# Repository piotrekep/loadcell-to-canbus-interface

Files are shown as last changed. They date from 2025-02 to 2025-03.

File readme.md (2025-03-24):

# Digital Scale with CAN Bus

This repository contains firmware for a digital scale system based on the ATmega328 microcontroller. Developed over 10 years ago, this project reads analog data via an ADS1234 ADC and transmits measurements over a CAN bus using an MCP2515 controller through an SPI interface.

## Overview

The firmware implements a digital weighing system that:

- **Acquires Data**: Reads four channels of analog data from an ADS1234 ADC.
- **CAN Bus Communication**: Transmits the acquired data in two separate CAN messages (IDs 0x250 and 0x251).
- **SPI Interface**: Uses custom SPI routines to communicate with both the CAN controller and the ADS1234.
- **Robust Operation**: Utilizes a watchdog timer and interrupt-driven routines to ensure reliable operation.

## Hardware Setup

### ATmega328
- **Microcontroller**: ATmega328
- **Clock Speed**: 20 MHz (FOSC = 20,000,000)

### ADS1234 ADC
- **Data Acquisition**:
  - **Input Selection**: Controlled via two pins on PORTC (A0 on PC1 and A1 on PC0).
  - **Gain Control**: Connected to PORTD (GAIN0 on PD1 and GAIN1 on PD2).
  - **Speed Control**: Connected to PC5.
  - **Data**: Read from PC2.
  - **Clock**: Driven from PC3.
  - **Power**: Controlled on PC4.
- **Channel Selection**: Four channels are read sequentially, with channels AIN1–AIN4 selected via software.

### CAN Bus (MCP2515)
- **Communication**: Uses the SPI interface.
  - **MOSI**: PB3
  - **SCK**: PB5
  - **Chip Select (CS)**: PB2
- **CAN Messaging**: Two messages are prepared and sent:
  - **Message 1 (ID 0x250)**: Contains data from channels AIN1 and AIN2.
  - **Message 2 (ID 0x251)**: Contains data from channels AIN3 and AIN4.

### UART (Debugging)
- **Serial Communication**: Basic serial routines are provided for debugging using UART0 at 115200 baud.

## Project Structure

```
.
├── ads1234/
│   ├── ads1234.c
│   └── ads1234.h
├── CAN_drv/
│   ├── can_drv.c
│   └── can_drv.h
├── SPI_drv/
│   └── SPIm328.c
├── twi/             (if applicable)
│   └── twi.c
├── uartsimple/
│   ├── uartsimple.c
│   └── usartsimple.h
├── types/
│   └── tdef.h
└── main.c
```

## Build Instructions

This project is configured for the AVR-GCC toolchain and was originally built using Atmel AVR Studio. Two build configurations are provided:

- **Debug**: Compiled with debugging symbols and optimization level O1.
- **Release**: Compiled with optimizations for size (-Os).

To compile the project from the command line, you might use:

```bash
avr-gcc -mmcu=atmega328p -Os -DF_CPU=20000000UL -o digital_scale.elf \
  main.c ads1234/ads1234.c CAN_drv/can_drv.c SPI_drv/SPIm328.c uartsimple/uartsimple.c
avr-objcopy -O ihex -R .eeprom digital_scale.elf digital_scale.hex
```

Be sure to adjust include paths and source files as needed.

## Flashing the Firmware

You can use your preferred AVR programmer (such as avrdude) to flash the firmware. For example:

```bash
avrdude -c usbtiny -p m328p -U flash:w:digital_scale.hex:i
```

## Configuration Details

- **Clock Speed**: Set to 20 MHz.
- **UART Baud Rate**: 115200 baud.
- **CAN Bus Baud Rate**: Configured using the `CAN_setBaud20` function. Baud rate options include 125, 250, and 500 kbps.
- **Watchdog Timer**: Enabled with a 2-second timeout to help ensure robust operation.

## PCB and Schematics

PCB layout and schematic files are located in the `wagapcb` directory. Multiple revisions exist:

- **waga**: Original layout files (`waga_can.brd`, `waga_can.sch`, and associated Gerber outputs).
- **waga v0.1**: First revision of the board, containing minor tweaks to layout and connectivity.
- **waga v0.2**: Second revision with updates for component placement and routing improvements.
- **waga v0.2stm**: A variant of the second revision intended for further prototyping.

Each folder contains EAGLE project files (`.brd`, `.sch`) and Gerber files (`.GBL`, `.GBO`, `.GTL`, etc.) for manufacturing. 

## Notes

- This project is a legacy codebase and may require updates for modern toolchains or hardware revisions.
- Detailed configuration settings (such as ADC channel selection and CAN bus setup) can be found within the source code files.

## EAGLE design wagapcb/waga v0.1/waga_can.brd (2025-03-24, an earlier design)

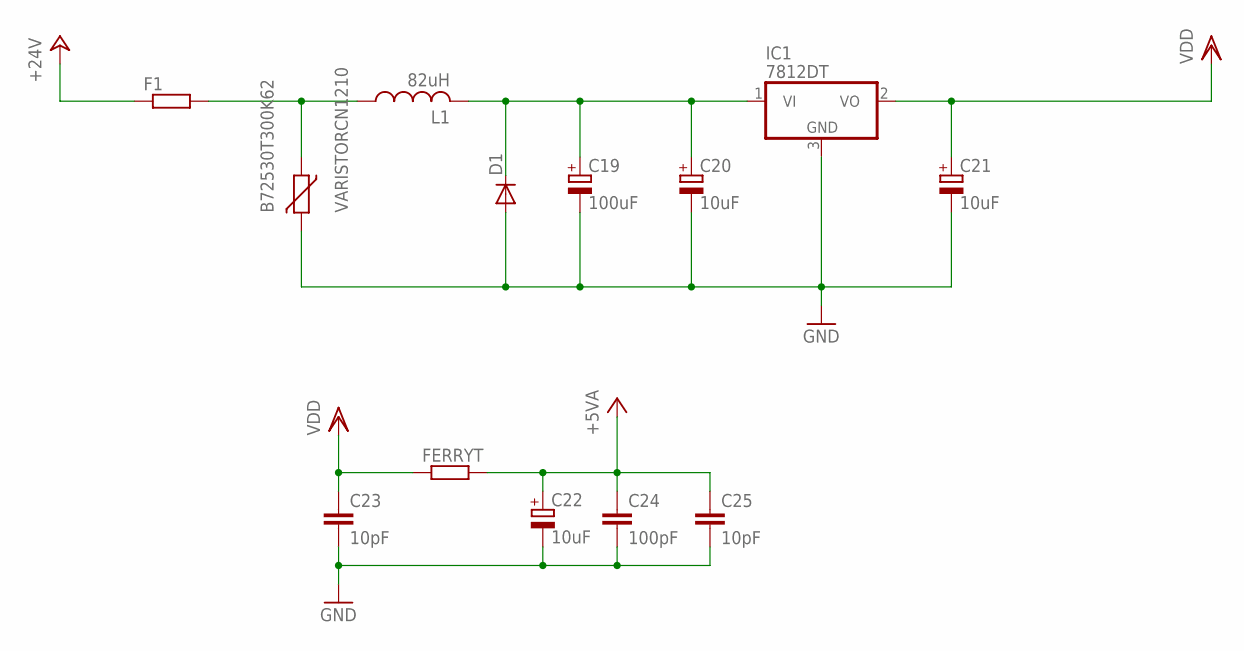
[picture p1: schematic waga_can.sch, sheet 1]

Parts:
B72530T300K62: VARISTORCN1210; CT/CN1210
C19: 100uF; 153CLV-0810
C20, C21, C22: 10uF; 153CLV-0605
C23, C25: 10pF; C0805
C24: 100pF; C0805
D1: DIODE-SMB; SMB
F1: R-EU_1812X7R; 1812X7R
FERRYT: R-EU_M0805; M0805
IC1: 7812DT; TO252
L1: 82uH; L4532P

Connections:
+5V: C22.+, C24.1, C25.1, FERRYT.2; also elsewhere on the board
+24V: F1.1; also elsewhere on the board
GND: B72530T300K62.2, C19.-, C20.-, C21.-, C22.-, C23.2, C24.2, C25.2, D1.A, IC1.3 (GND); also elsewhere on the board
unnamed: C19.+, C20.+, D1.C, IC1.1 (VI), L1.2
unnamed: B72530T300K62.1, F1.2, L1.1
VDD: C21.+, C23.1, FERRYT.1, IC1.2 (VO); also elsewhere on the board

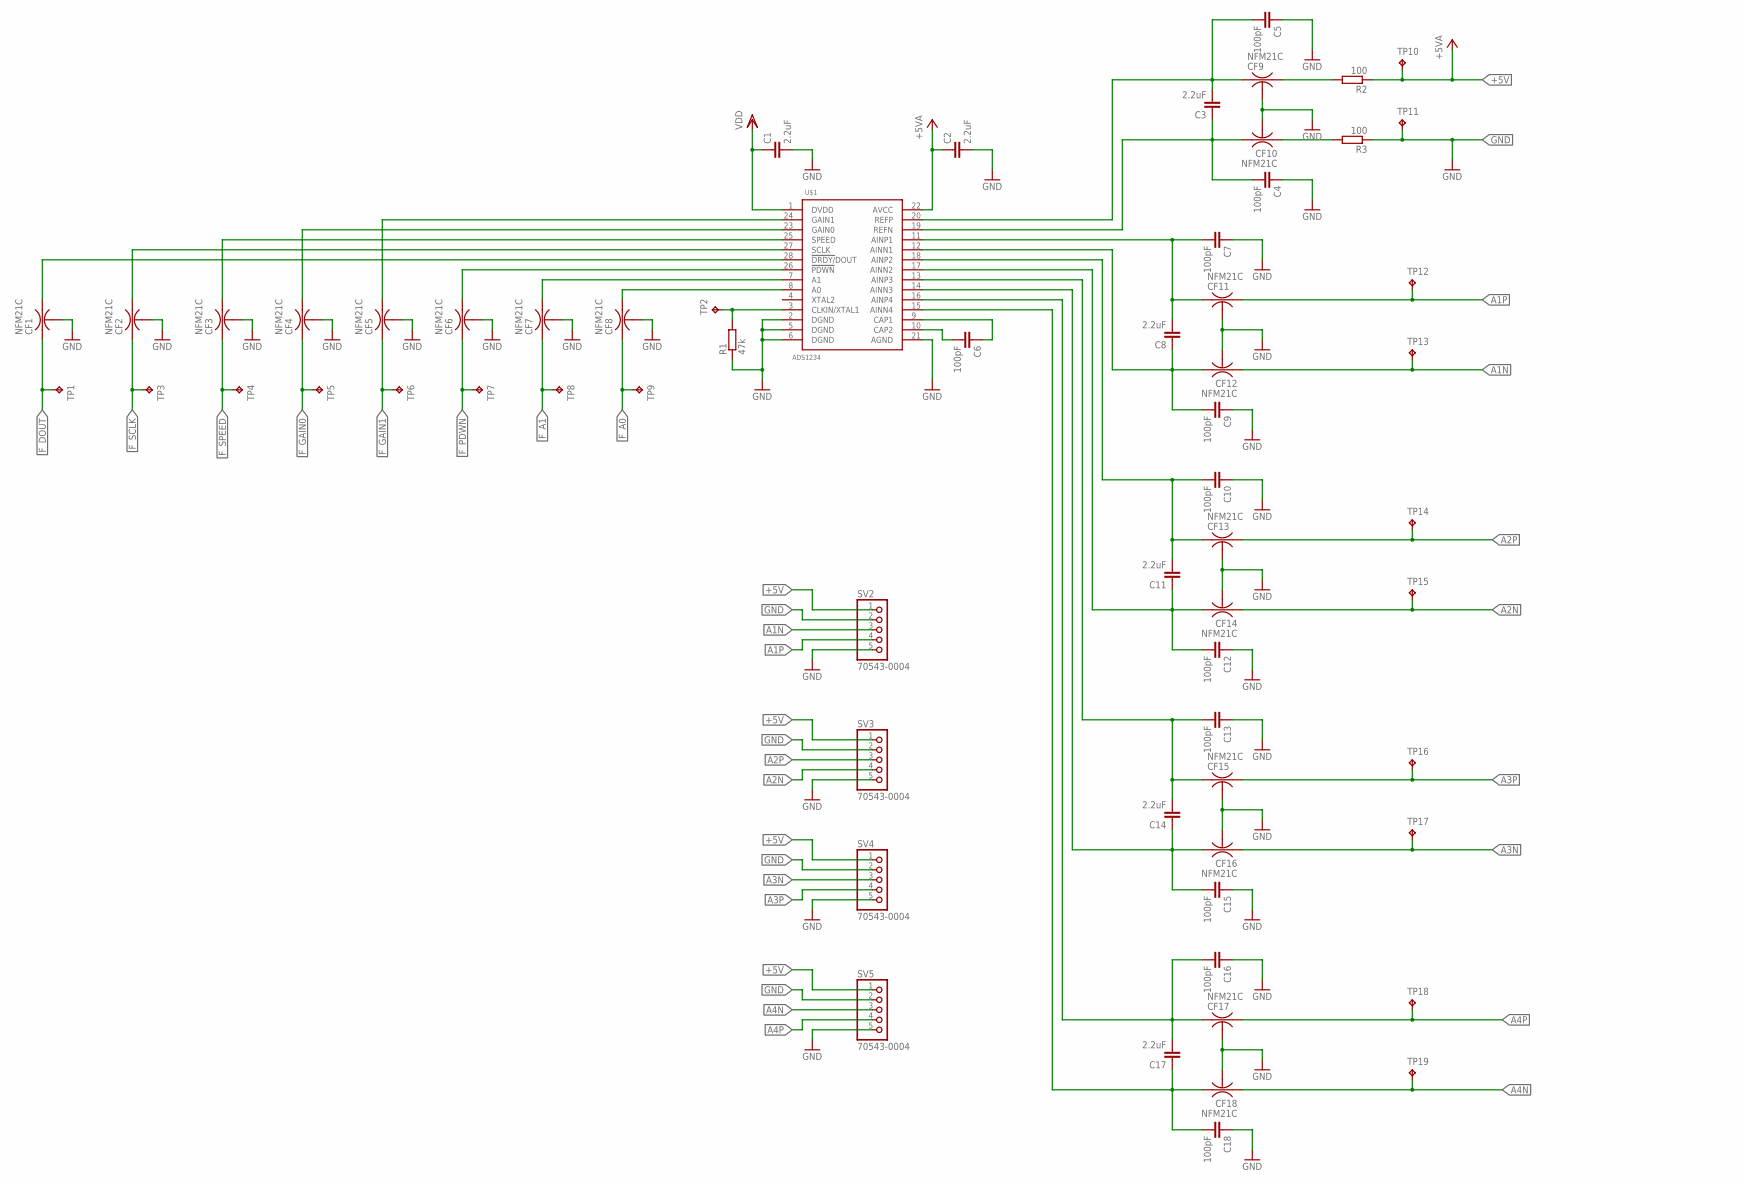
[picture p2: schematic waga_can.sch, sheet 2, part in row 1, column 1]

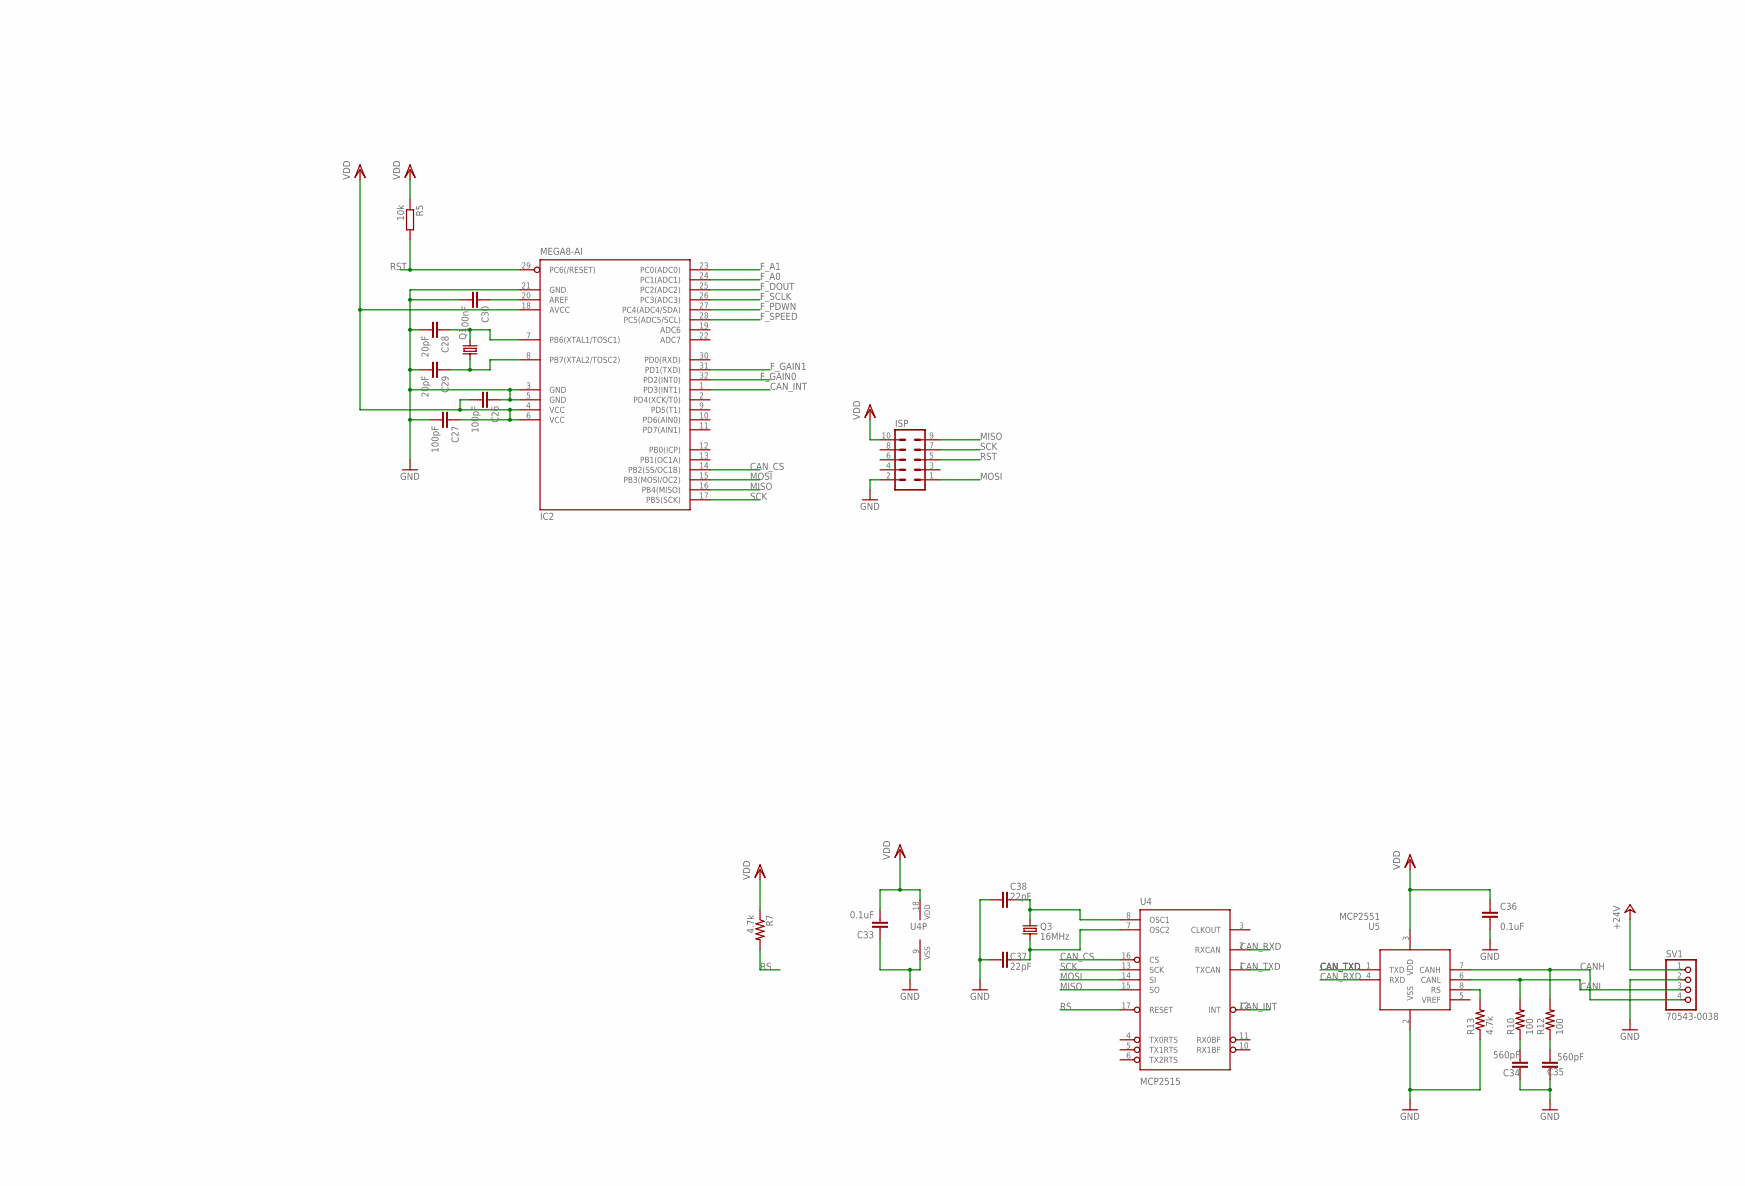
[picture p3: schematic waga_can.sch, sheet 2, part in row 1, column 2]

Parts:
C1, C2, C3, C8, C11, C14, C17: 2.2uF; C0805K
C4, C5, C6, C7, C9, C10, C12, C13, C15, C16, C18, C26, C27: 100pF; C0805K
C28, C29: 20pF; C0805K
C30: 100nF; C0805K
C33, C36: 0.1uF; 0603-CAP
C34, C35: 560pF; 0603-CAP
C37, C38: 22pF; 0603-CAP
CF1, CF2, CF3, CF4, CF5, CF6, CF7, CF8, CF9, CF10, CF11, CF12, CF13, CF14, CF15, CF16, CF17, CF18: NFM21C
IC2: MEGA8-AI; TQFP32-08
ISP: ML10
Q1: CRYSTALCTS406; CTS406
Q3: 16MHz; CRYSTAL-SMD-5X3
R1: 47k; R0805
R2, R3: 100; R0805
R5: 10k; R0805
R7, R13: 4.7k; 0603-RES
R10, R12: 100; 0603-RES
SV1: 70543-0038
SV2, SV3, SV4, SV5: 70543-0004
TP1, TP2, TP3, TP4, TP5, TP6, TP7, TP8, TP9, TP10, TP11, TP12, TP13, TP14, TP15, TP16, TP17, TP18, TP19: TPTP06R; TP06R
U4: MCP2515; SO-18W
U5: MCP2551; SO-08M
U$1: ADS1234; TSSOP-28

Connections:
+5V: C2.1, R2.1, SV2.1, SV3.1, SV4.1, SV5.1, TP10.TP, U$1.22 (AVCC); also elsewhere on the board
+24V: SV1.1; also elsewhere on the board
A0: CF8.3, U$1.8 (A0)
A1: CF6.3, U$1.26 (!PDWN)
A1N: CF12.1, SV2.3, TP13.TP
A1P: CF11.3, SV2.4, TP12.TP
A2N: CF14.1, SV3.4, TP15.TP
A2P: CF13.3, SV3.3, TP14.TP
A3N: CF16.1, SV4.3, TP17.TP
A3P: CF15.3, SV4.4, TP16.TP
A4N: CF18.1, SV5.3, TP19.TP
A4P: CF17.3, SV5.4, TP18.TP
CANH: R12.2, SV1.4, U5.7 (CANH)
CANL: R10.2, SV1.3, U5.6 (CANL)
CAN_CS: IC2.14 (PB2(SS/OC1B)), U4.16 (CS)
CAN_INT: IC2.1 (PD3(INT1)), U4.12 (INT)
CAN_RXD: U4.2 (RXCAN), U5.4 (RXD)
CAN_TXD: U4.1 (TXCAN), U5.1 (TXD)
DOUT: CF1.3, U$1.28 (!DRDY/!DOUT)
F_A0: CF8.1, IC2.24 (PC1(ADC1)), TP9.TP
F_A1: CF7.1, IC2.23 (PC0(ADC0)), TP8.TP
F_DOUT: CF1.1, IC2.25 (PC2(ADC2)), TP1.TP
F_GAIN0: CF4.1, IC2.32 (PD2(INT0)), TP5.TP
F_GAIN1: CF5.1, IC2.31 (PD1(TXD)), TP6.TP
F_PDWN: CF6.1, IC2.27 (PC4(ADC4/SDA)), TP7.TP
F_SCLK: CF2.1, IC2.26 (PC3(ADC3)), TP3.TP
F_SPEED: CF3.1, IC2.28 (PC5(ADC5/SCL)), TP4.TP
GAIN0: CF4.3, U$1.23 (GAIN0)
GAIN1: CF5.3, U$1.24 (GAIN1)
GND: C1.2, C2.2, C4.1, C5.1, C7.1, C9.1, C10.1, C12.1, C13.1, C15.1, C16.1, C18.1, C26.1, C27.2, C28.2, C29.2, C30.2, C33.1, C34.1, C35.1, C36.1, C37.1, C38.1, CF1.2@1 (2), CF1.2@2 (2), CF2.2@1 (2), CF2.2@2 (2), CF3.2@1 (2), CF3.2@2 (2), CF4.2@1 (2), CF4.2@2 (2), CF5.2@1 (2), CF5.2@2 (2), CF6.2@1 (2), CF6.2@2 (2), CF7.2@1 (2), CF7.2@2 (2), CF8.2@1 (2), CF8.2@2 (2), CF9.2@1 (2), CF9.2@2 (2), CF10.2@1 (2), CF10.2@2 (2), CF11.2@1 (2), CF11.2@2 (2), CF12.2@1 (2), CF12.2@2 (2), CF13.2@1 (2), CF13.2@2 (2), CF14.2@1 (2), CF14.2@2 (2), CF15.2@1 (2), CF15.2@2 (2), CF16.2@1 (2), CF16.2@2 (2), CF17.2@1 (2), CF17.2@2 (2), CF18.2@1 (2), CF18.2@2 (2), IC2.3 (GND), IC2.5 (GND), IC2.21 (GND), ISP.2, R1.1, R3.1, R13.1, SV1.2, SV2.2, SV2.5, SV3.2, SV3.5, SV4.2, SV4.5, SV5.2, SV5.5, TP11.TP, U4.9 (VSS), U5.2 (VSS), U$1.2 (DGND), U$1.5 (DGND), U$1.6 (DGND), U$1.21 (AGND); also elsewhere on the board
MISO: IC2.16 (PB4(MISO)), ISP.9, U4.15 (SO)
MOSI: IC2.15 (PB3(MOSI/OC2)), ISP.1, U4.14 (SI)
unnamed: C30.1, IC2.20 (AREF)
unnamed: C34.2, R10.1
unnamed: CF7.3, U$1.7 (A1)
unnamed: C28.1, IC2.7 (PB6(XTAL1/TOSC1)), Q1.3 (2)
unnamed: R1.2, TP2.TP, U$1.3 (CLKIN/XTAL1)
unnamed: C29.1, IC2.8 (PB7(XTAL2/TOSC2)), Q1.1
unnamed: C3.2, C5.2, CF9.1, U$1.20 (REFP)
unnamed: C3.1, C4.2, CF10.3, U$1.19 (REFN)
unnamed: C14.1, C15.2, CF16.3, U$1.14 (AINN3)
unnamed: CF9.3, R2.2
unnamed: CF10.1, R3.2
unnamed: C6.2, U$1.10 (CAP2)
unnamed: C6.1, U$1.9 (CAP1)
unnamed: C35.2, R12.1
unnamed: C7.2, C8.2, CF11.1, U$1.11 (AINP1)
unnamed: C8.1, C9.2, CF12.3, U$1.12 (AINN1)
unnamed: C10.2, C11.2, CF13.1, U$1.18 (AINP2)
unnamed: C11.1, C12.2, CF14.3, U$1.17 (AINN2)
unnamed: R13.2, U5.8 (RS)
unnamed: C13.2, C14.2, CF15.1, U$1.13 (AINP3)
unnamed: C38.2, Q3.3 (2), U4.8 (OSC1)
unnamed: C37.2, Q3.1, U4.7 (OSC2)
unnamed: C16.2, C17.2, CF17.1, U$1.16 (AINP4)
unnamed: C17.1, C18.2, CF18.3, U$1.15 (AINN4)
RS: R7.2, U4.17 (RESET)
RST: IC2.29 (PC6(/RESET)), ISP.5, R5.2
SCK: IC2.17 (PB5(SCK)), ISP.7, U4.13 (SCK)
SCLK: CF2.3, U$1.27 (SCLK)
SPEED: CF3.3, U$1.25 (SPEED)
VDD: C1.1, C26.2, C27.1, C33.2, C36.2, IC2.4 (VCC), IC2.6 (VCC), IC2.18 (AVCC), ISP.10, R5.1, R7.1, U4.18 (VDD), U5.3 (VDD), U$1.1 (DVDD); also elsewhere on the board

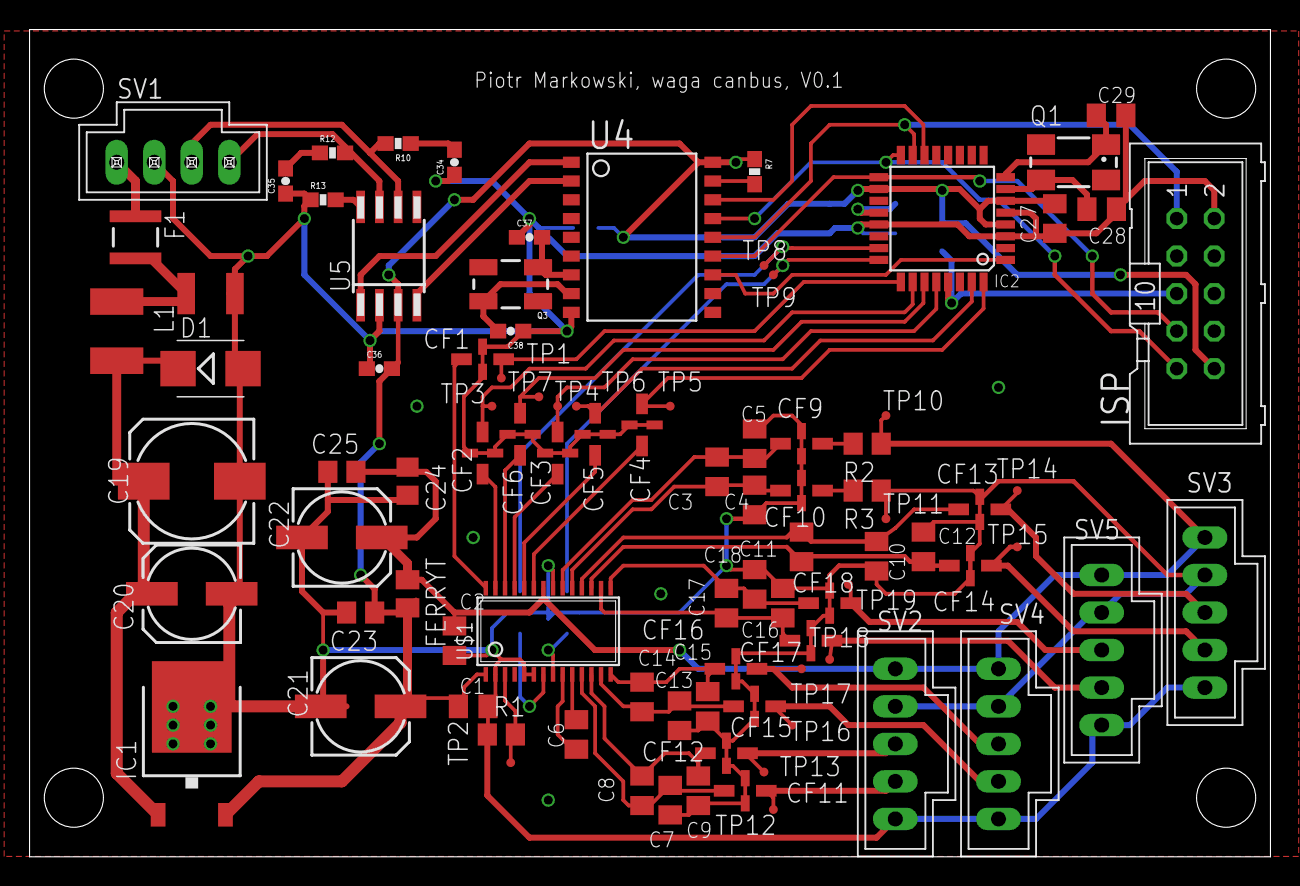
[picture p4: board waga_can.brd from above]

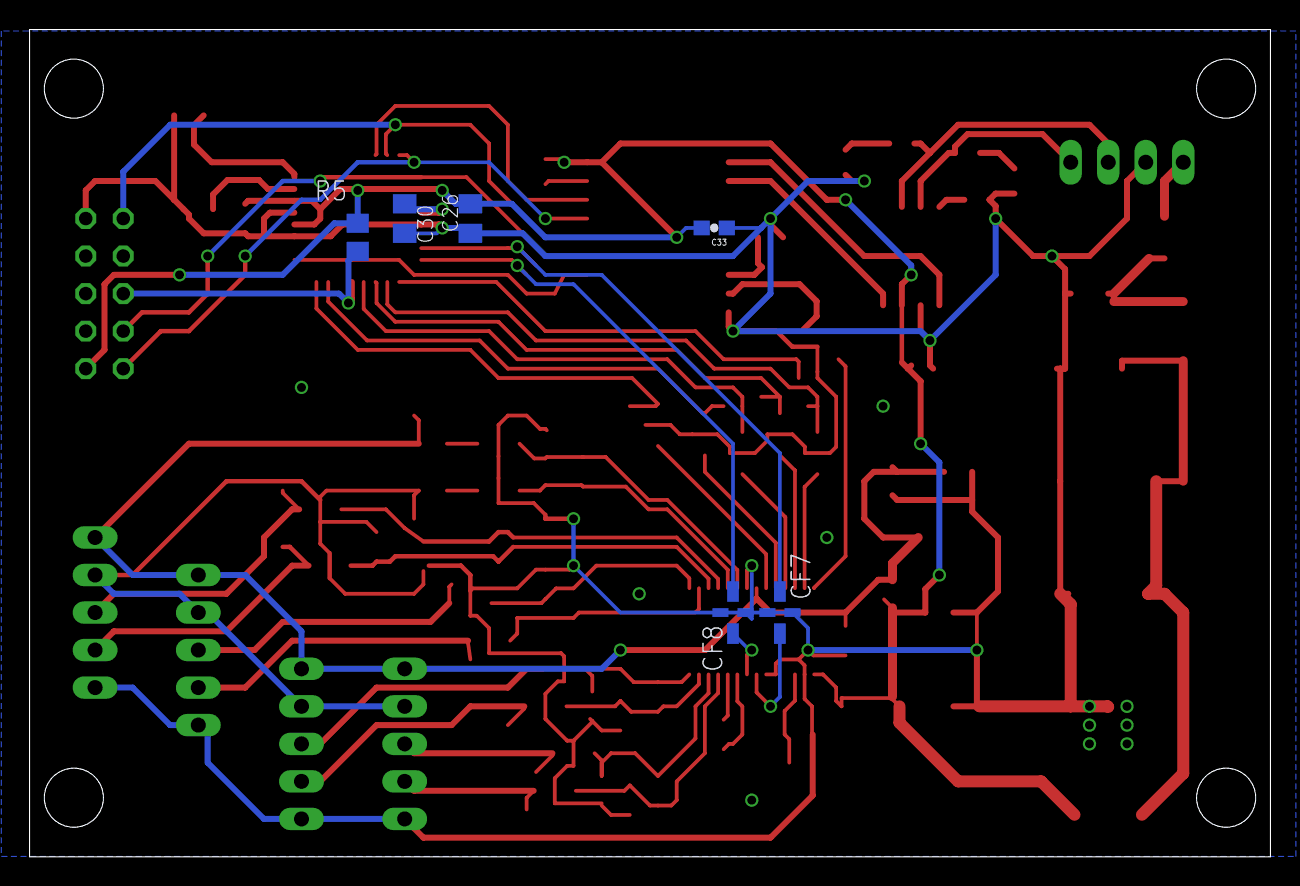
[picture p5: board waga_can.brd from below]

Board: 2 copper layers, 84.0 x 56.0 mm, 99 parts (6 on the bottom side), 64 nets.

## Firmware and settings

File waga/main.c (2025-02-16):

/*
 * j1939ecu.c
 *
 * Created: 2017-05-02 16:46:30
 *  Author: Ja
 */ 
#define FOSC 20000000// Clock Speed
#define BAUD 115200
#define MYUBRR FOSC/16/BAUD-1


#include <avr/io.h>
#include <avr/interrupt.h>
#include <inttypes.h>
#include <util/delay.h>
#include <avr/wdt.h>

#include "types/tdef.h"
#include "SPI_drv/SPIm328.h"
#include "CAN_drv//can_drv.h"
#include "ads1234/ads1234.h"


ISR(INT0_vect );
ISR(TIMER0_COMPA_vect );


volatile CAN_msg tx_msg1;
volatile CAN_msg tx_msg2;
volatile uint32_t i=0;
volatile uint8_t data_rdy=0;
	
int main(void)
{
   	wdt_enable(WDTO_2S);
	 
   	tx_msg1.ident=0x250; //message 1 ID, supports only standard id's adding extended should be trivial
   	tx_msg1.RTR=0;
   	tx_msg1.DLC=8;
	   
	tx_msg2.ident=0x251; //message 2 ID
	tx_msg2.RTR=0;
	tx_msg2.DLC=8;
  
// can transmit interupt timer
	TCCR0A |= (1<<WGM01);
	TCCR0B |= (1<<CS02) | (0<<CS01) | (1<<CS00);
	TIMSK0 |= (1<<OCIE0A); 
	OCR0A=195; 
	
	EIMSK |= (1<<INT1);
	//EIMSK = 0;
	DDRD=0;
	PORTD=0;

	DDRD |= (1<<PIND4);
	PORTD |= (1<<PORTD0);
	   
	   
	SPI_MasterInit();
   	CAN_reset();
	 _delay_ms(10);
	//can init
	CAN_setBaud20(2);
	CAN_int_en(0x21);
	//CAN_int_en(0x03);
	CAN_mode(0);
	
		if(CAN_check_mode()==0)
		{
					//todo: add error handling
		}


	ADS1234_init();
	ADS1234_PWR(ADS1234_PWR_ON);
	ADS1234_input_select(ADS1234_AIN1);
	ADS1234_Speed(ADS1234_HIGH_SPEED);
	ADS1234_gain_select(ADS1234_GAIN128);

	sei();
 
 // uint32_t temp=0;
  uint32_t d0=0;
  uint32_t d1=0;
  uint32_t d2=0;
  uint32_t d3=0;
  
 // int32_t srednia=0;
 
  
  
    while(1)
    {
       wdt_reset();
	   
	 
	 ADS1234_input_select(ADS1234_AIN1);  
	 while(((DATA_PORT & (1<<DATA_PIN))!=0));
	d0=ADS1234_read();
		//srednia=temp;
			d0=d0<<8;
			d0=d0>>8;
			// srednia=temp<<8;
			// srednia=srednia>>8;
			tx_msg1.data[0]=d0;
			tx_msg1.data[1]=d0>>8;
			tx_msg1.data[2]=d0>>16;
			tx_msg1.data[3]=d0>>24;
					
	 ADS1234_input_select(ADS1234_AIN2);
	 while(((DATA_PORT & (1<<DATA_PIN))!=0));
	 d1=ADS1234_read();
	 //srednia=temp;
	 	 d1=d1<<8;
	 	 d1=d1>>8;
		 tx_msg1.data[4]=d1;
		 tx_msg1.data[5]=d1>>8;
		 tx_msg1.data[6]=d1>>16;
		 tx_msg1.data[7]=d1>>24;

	 ADS1234_input_select(ADS1234_AIN3);
	 while(((DATA_PORT & (1<<DATA_PIN))!=0));
	 d2=ADS1234_read();
	 d2=d2<<8;
	 d2=d2>>8;
		 tx_msg2.data[0]=d2;
		 tx_msg2.data[1]=d2>>8;
		 tx_msg2.data[2]=d2>>16;
		 tx_msg2.data[3]=d2>>24;
	 
	 ADS1234_input_select(ADS1234_AIN4);
	 while(((DATA_PORT & (1<<DATA_PIN))!=0));
	 d3=ADS1234_read();
	 //srednia=temp;
	 	 d3=d3<<8;
	 	 d3=d3>>8;
		 tx_msg2.data[4]=d3;
		 tx_msg2.data[5]=d3>>8;
		 tx_msg2.data[6]=d3>>16;
		 tx_msg2.data[7]=d3>>24; 
	 
data_rdy=1;

	   
    }
}




ISR(INT1_vect )
{
	uint8_t flag;

	flag = CAN_get_pint();


	switch(flag)
	{
		case 1: //error interrupt
		CAN_clear_int(5);
		break;
		
		case 2: //wake up
		CAN_clear_int(6);
		
		break;
		case 3: //TXB0 empty		
		CAN_clear_int(2);
		
		break;
		case 4: //TXB1 empty
		CAN_clear_int(3);
		
		break;
		case 5: //TXB2 empty
		CAN_clear_int(4);
		
		break;
		case 6: //RXB0 full
		CAN_clear_int(0);
		
		
		break;
		case 7: //RXB1 full
		CAN_clear_int(1);
		
		
		break;
	}


}



ISR(TIMER0_COMPA_vect ) //10ms
{

// 	   

if((i>=10) & (data_rdy>0))
{
		CAN_TX_Write(tx_msg1,0);
		CAN_RTS(0);
		CAN_TX_Write(tx_msg2,1);
		CAN_RTS(1);
i=0;
data_rdy=0;
}
	   
	i++;

}

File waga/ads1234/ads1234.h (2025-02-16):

/*
 * ads1234.h
 *
 * Created: 2017-06-29 14:13:18
 *  Author: Ja
 */ 


#ifndef ADS1234_H_
#define ADS1234_H_

#include <inttypes.h>
#include <avr/io.h>

#define GAIN0_PORT PORTD
#define GAIN1_PORT PORTD
#define GAIN0_PIN 1
#define GAIN1_PIN 2
#define GAIN0_DDR DDRD
#define GAIN1_DDR DDRD


#define A0_PORT PORTC
#define A1_PORT PORTC
#define A0_PIN 1
#define A1_PIN 0
#define A0_DDR DDRC
#define A1_DDR DDRC

#define SPEED_PORT PORTC
#define SPEED_PIN 5
#define SPEED_DDR DDRC

#define DATA_PORT PINC
#define DATA_PIN 2
#define DATA_DDR DDRC

#define CLK_PORT PORTC
#define CLK_PIN 3
#define CLK_DDR DDRC


#define PWR_PORT PORTC
#define PWR_PIN 4
#define PWR_DDR DDRC



#define ADS1234_AIN1 0
#define ADS1234_AIN2 2
#define ADS1234_AIN3 1
#define ADS1234_AIN4 3


#define ADS1234_GAIN1 0
#define ADS1234_GAIN2 2
#define ADS1234_GAIN64 1
#define ADS1234_GAIN128 3


#define ADS1234_LOW_SPEED 0
#define ADS1234_HIGH_SPEED 1


#define ADS1234_PWR_ON 1
#define ADS1234_PWR_OFF 0

void ADS1234_init(void);
void ADS1234_PWR(uint8_t stat);
void ADS1234_input_select(uint8_t input);
void ADS1234_gain_select(uint8_t gain);
void ADS1234_Speed(uint8_t spd);
uint32_t ADS1234_read(void);
void ADS1234_clk_high(void);
void ADS1234_clk_low(void);

#endif /* ADS1234_H_ */
